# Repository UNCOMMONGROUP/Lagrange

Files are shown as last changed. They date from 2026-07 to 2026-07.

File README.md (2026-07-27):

# Lagrange USB-UART Bridge

An open-source USB CDC-ACM to UART bridge built around the Renesas RA2L2 MCU.

## Why another USB-UART adapter?

Because the cheap ones keep letting us down.

If you have spent any time bringing up embedded hardware, you know the failure
modes: the adapter enumerates fine for an hour and then silently stops passing
data, the COM port vanishes mid-flash and takes the bootloader session with it,
throughput collapses under sustained traffic, or the driver decides today is the
day it does not want to install. Mass-market clone adapters — the CH340-class
parts you find on every marketplace — are cheap for a reason, and when a debug
session depends on the serial link staying up, that cost shows up somewhere
else. We got tired of blaming our own firmware for problems that turned out to
be the adapter, so we built one we could actually trust.

This design is meant to be boring in the best way: stable enumeration, reliable
sustained throughput up to 1.5 Mbps, and behaviour you can reason about because
the firmware is right here in this repository.

## Why an MCU instead of a dedicated bridge chip?

We deliberately did **not** use a fixed-function bridge IC such as the FT232.

A dedicated bridge chip does exactly one thing, and if you need it to do
anything else, you buy a different chip and redesign the board. By building on
the RA2L2 — a general-purpose Arm Cortex-M23 MCU with native USB — the
conversion logic lives in firmware instead of in silicon. The same hardware can
be retargeted to other interfaces: I2C, SPI, CAN, RS-485, or a protocol-aware
debug tool that does more than shuffle bytes. Adding an interface becomes a
firmware release rather than a new product.

It also means the behaviour is inspectable and fixable. If something needs to
change — buffering strategy, flow control, line-coding handling — the source is
in this repository and you can change it. That is not an option with a
closed-function bridge chip.

## Features

- USB 2.0 Full-Speed CDC-ACM (virtual COM port, no vendor driver required)
- Baud rates up to 1.5 Mbps with 0% error at the target clock
- DTC-driven UART path with a 1 ms idle flush, so sustained traffic does not
  drown the CPU in per-byte interrupts
- Live reconfiguration of baud rate, parity, stop bits and data bits via CDC
  `SET_LINE_CODING`
- TX and RX activity LEDs
- USB-C connector with proper CC termination
- ESD protection on both the USB and UART sides
- Molex Pico-Lock connector on the UART side
- 3D-printed (SLS) enclosure; design files included

## Hardware

| Item | Detail |
| --- | --- |
| MCU | Renesas RA2L2 (R7FA2L2074CNH), Arm Cortex-M23 |
| System clock | 48 MHz HOCO — no external crystal required |
| UART | SCI1 |
| USB | Full-Speed device, USB-C receptacle |
| UART connector | Molex Pico-Lock 205338-0004 |
| PCB | 40 × 19 mm, single-sided assembly |

## Repository layout

```
firmware/    e2 studio project (Renesas FSP)
hardware/    schematic, PCB design files, enclosure STEP
```

## Building the firmware

The firmware is an e2 studio project based on the Renesas Flexible Software
Package (FSP). Open the project in e2 studio, run **Generate Project Content**
from the FSP Configurator, and build.

## License

- **Firmware:** MIT — see [LICENSE](LICENSE)
- **Hardware:** CERN-OHL-S v2 — see [LICENSE-hardware](LICENSE-hardware)

Portions of the firmware are provided by the Renesas Flexible Software Package
and are licensed under BSD-3-Clause by Renesas Electronics Corporation; the
original copyright notices are retained in those files.

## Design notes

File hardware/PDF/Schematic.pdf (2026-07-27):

# Molex Picoblade ²KR1

# USB-C / Data + Power

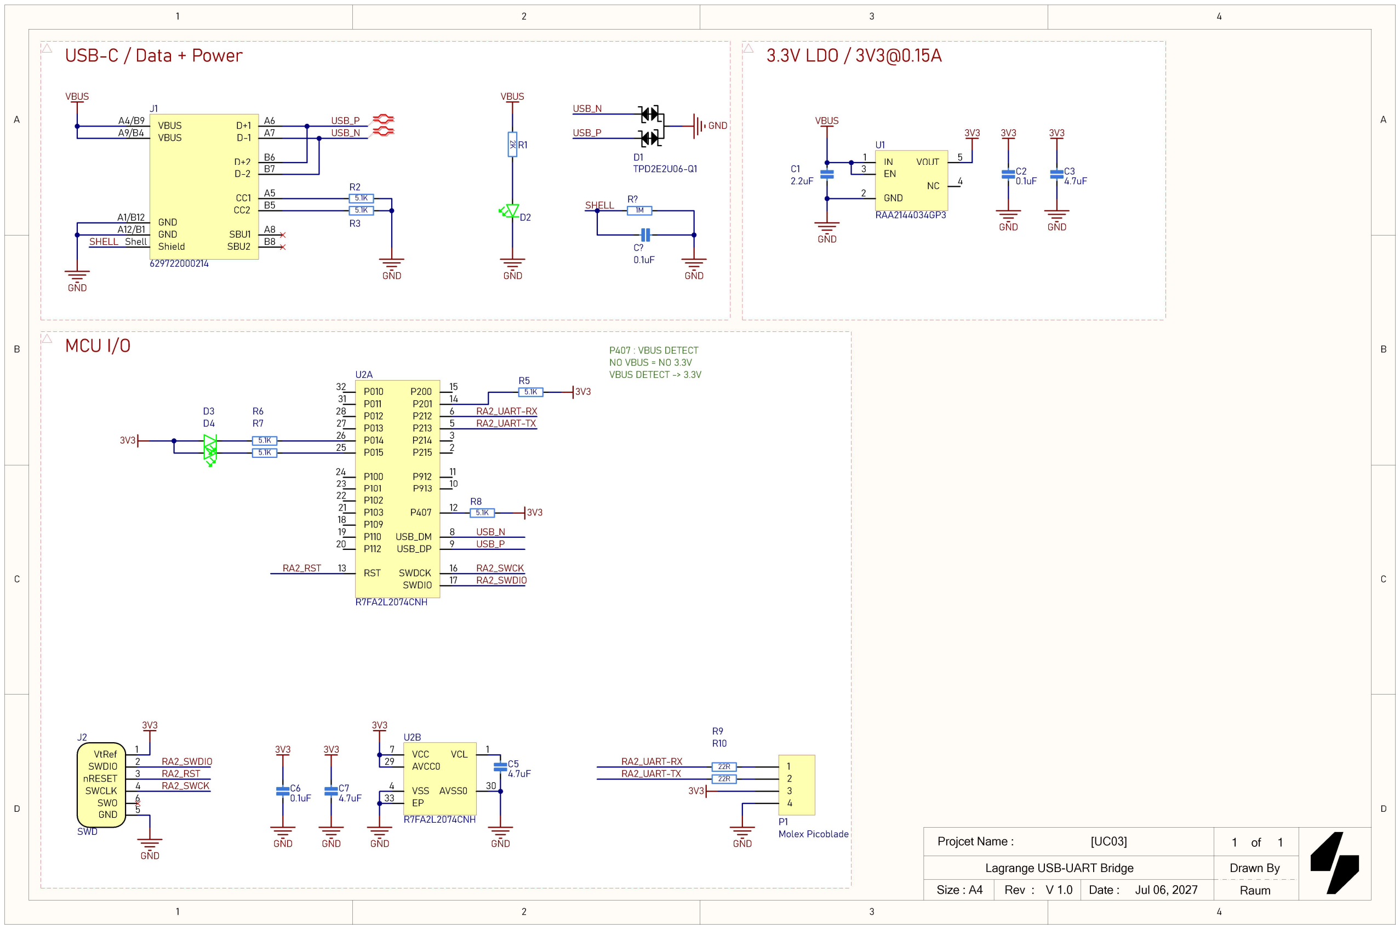
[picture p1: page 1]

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
[UC03] | 1 | 1
V 1.0 | Jul 06, 2027

## Projcet Name :

## Size : A4 Rev :

of

## Date :

## Drawn By

## Raum

## Lagrange USB-UART Bridge

1
2
3
4

P1

D2

GND

VBUS

C1
2.2uF

GND

C2
0.1uF

GND

C3
4.7uF

GND

IN 1

GND 2

EN 3
NC | 4
VOUT | 5

U1

RAA2144034GP3

3V3 | 3V3 | 3V3

GND

5.1K

R2

5.1K
R3

GND

VBUS

VBUS

# MCU I/O

P215 | 2
P214 | 3
P213 | 5
P212 | 6
USB_DM | 8
USB_DP | 9
P913 | 10
P912 | 11
P407 | 12

RST 13

P201 | 14
P200 | 15
SWDCK | 16
SWDIO | 17

P109 18
P110 19
P112 20

P103 21

P102 22

P101 23

P100 24

P015 25

P014 26

P013 27

P012 28

P011 31

P010 32

U2A

R7FA2L2074CNH

VCL 1

VSS 4

VCC 7
AVCC0 29

AVSS0 30
EP 33

U2B

R7FA2L2074CNH

3V3

GND | GND C5 4.7uF

C6
0.1uF

GND

C7
4.7uF

GND

3V3 | 3V3 VtRef | 1
SWDIO | 2
nRESET | 3
SWCLK | 4
GND | 5
SWO | 6

J2

SWD

3V3

GND

RA2_SWDIO

RA2_SWCK

RA2_RST

RA2_RST
RA2_SWDIO

RA2_SWCK

GND A1/B12

VBUS A4/B9

CC1 | A5
D+1 | A6
D-1 | A7
SBU1 | A8

VBUS A9/B4

GND A12/B1

CC2 | B5
D+2 | B6
D-2 | B7
SBU2 | B8 Shield Shell

J1

629722000214

USB_P
USB_N

USB_P

USB_N

5.1K | 3V3

R8

RA2_UART-TX

RA2_UART-RX

# 3.3V LDO / 3V3@0.15A

GND
USB_P

USB_N

RA2_UART-TX

RA2_UART-RX | 22R R9

22R

R10

3V3

GND

5.1K | 3V3

R5

D1
TPD2E2U06-Q1
3V3 | 5.1K

R6

5.1K

R7

D3
D4

1M

R?

C?
0.1uF

SHELL

SHELL

GND

P407 : VBUS DETECT
NO VBUS = NO 3.3V
VBUS DETECT -> 3.3V

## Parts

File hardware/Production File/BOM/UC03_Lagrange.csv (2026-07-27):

Designator | Name | Description | Footprint | LibRef | Quantity
C1 | 2.2uF | Ceramic MLCC CAP | CAPC1608X90N_2 | CAP_MLCC | 1
C2, C4, C6 | 0.1uF | Ceramic MLCC CAP | CAPC1608X90N_2 | CAP_MLCC | 3
C3, C5, C7 | 4.7uF | Ceramic MLCC CAP | CAPC1608X90N_2 | CAP_MLCC | 3
D1 | TPD2E2U06-Q1 | Automotive Dual-Channel High-Speed ESD Protection Device | SC70_3 | TPD2E2U06-Q1 | 1
D2, D3, D4 | GRN | CHIP LED GREEN | LED-0603-GREEN | LED_GREEN | 3
J1 | 629722000214 | WR-COM USB 2.0 Type C Receptacle Horizontal SMT | 629722000214 | 629722000214 | 1
P1 | JST PA | Header, 4-Pin | 2053380004 | Header 4 | 1
R1 | 2K | Chip FIlm Resistor | RESC1608X55N_2 | R_Film_Chip | 1
R2, R3, R5, R6, R7, R8 | 5.1K | Chip FIlm Resistor | RESC1608X55N_2 | R_Film_Chip | 6
R4 | 1M | Chip FIlm Resistor | RESC1608X55N_2 | R_Film_Chip | 1
R9, R10 | 22R | Chip FIlm Resistor | RESC1608X55N_2 | R_Film_Chip | 2
U1 | RAA2144034GP3 | Low Iq Current LDO Regulator with Fixed 3.3V Output | SOT23-5 | RAA2144034GP3 | 1
U2 | R7FA2L2074CNH | Ultra low power 48 MHz Arm¢ç Cortex¢ç-M23 core, up to 128-KB code flash memory, 16-KB SRAM, USB 2.0 Full-Speed module (USBFS), USB Type-C¢ç interface (USBCC), 12-bit A/D Converter, Security and Safety features | ALLEGRO QFN-32 ET | R7FA2L2074CNH | 1

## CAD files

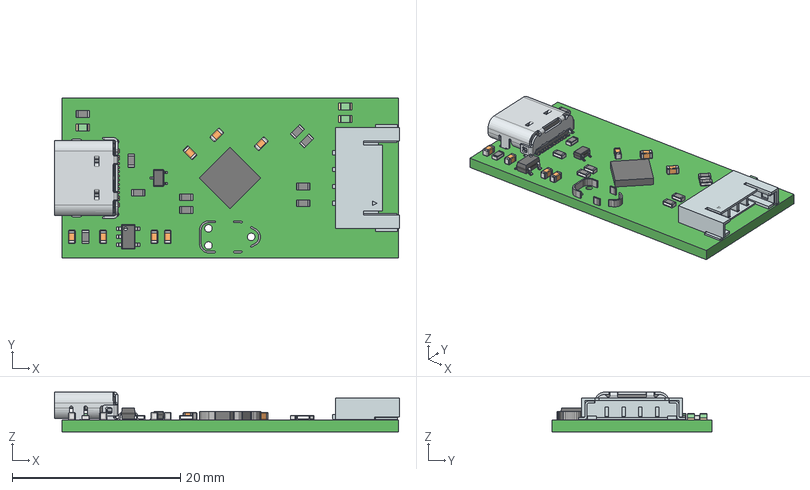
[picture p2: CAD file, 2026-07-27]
hardware/3D STEP/UC03_Lagrange.step
41.0 x 19.0 x 4.75 mm
LED 0603 APT1608 GREEN x 3
BODY-SOT
LEAD-SOT x 3
PIN1-ID
Extruded x 5
SOT23-5
629722000214_Housing
629722000214_Pin1_Top
629722000214_Pin4_Bottom
629722000214_Pin4_Top x 2
629722000214_Pin1_Bottom
629722000214_Pin3_Bottom
629722000214_Pin3_Top
629722000214_Pin2_Top
629722000214_Pin2_Bottom
629722000214_Pin1_Top_mir
629722000214_Pin1_Bottom_mir
629722000214_Pin2_Top_mir
629722000214_Pin2_Bottom_mir
629722000214_Pin3_Top_mir
629722000214_Pin3_Bottom_mir
629722000214_Pin4_Bottom_mir
629722000214_Shielding2
629722000214_Shielding

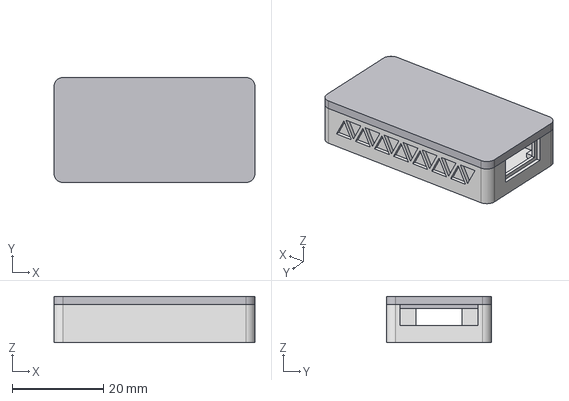
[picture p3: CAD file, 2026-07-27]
hardware/Enclouser/Lagrange_case.step
44.0 x 23.0 x 10.1 mm
tray
lid

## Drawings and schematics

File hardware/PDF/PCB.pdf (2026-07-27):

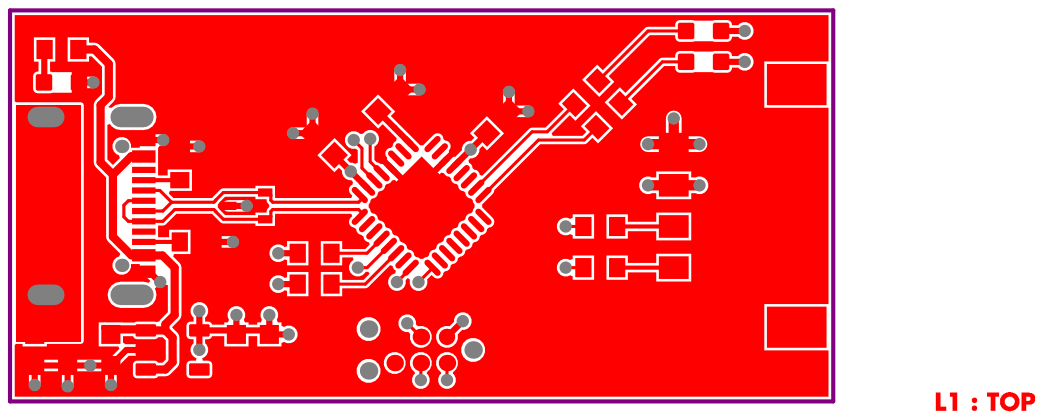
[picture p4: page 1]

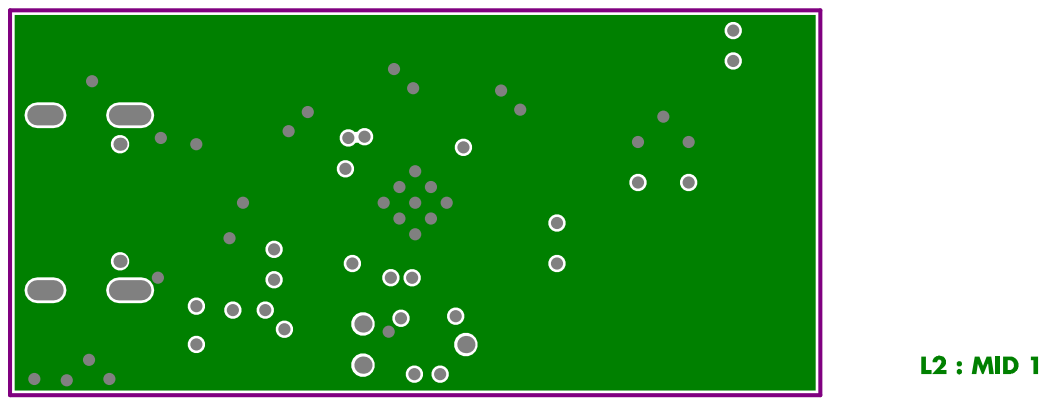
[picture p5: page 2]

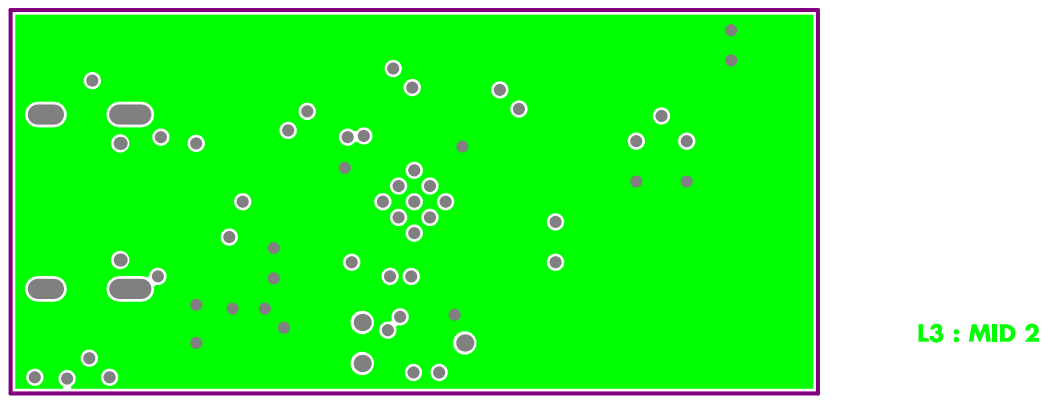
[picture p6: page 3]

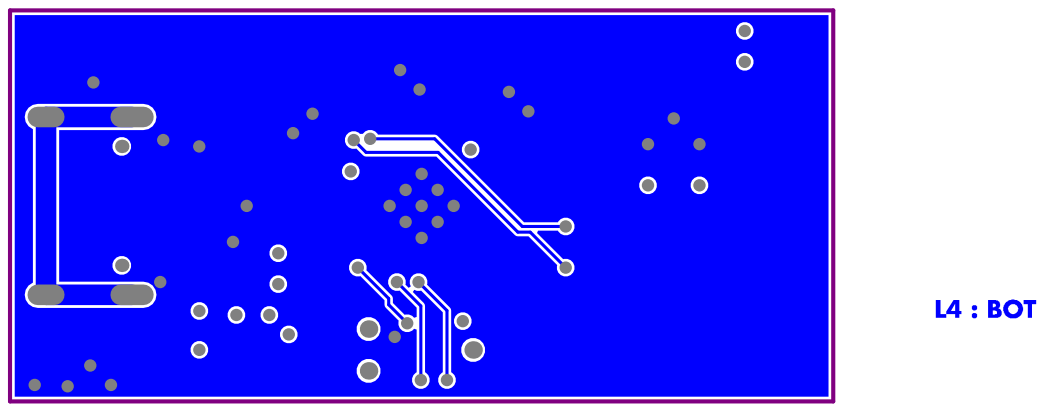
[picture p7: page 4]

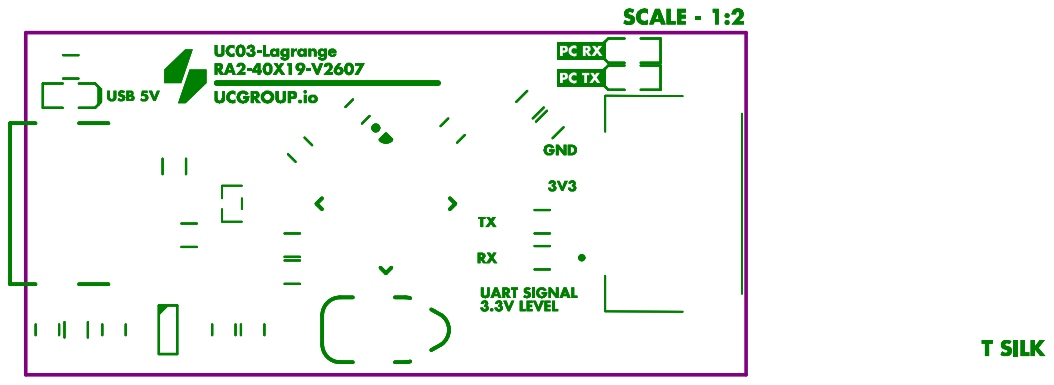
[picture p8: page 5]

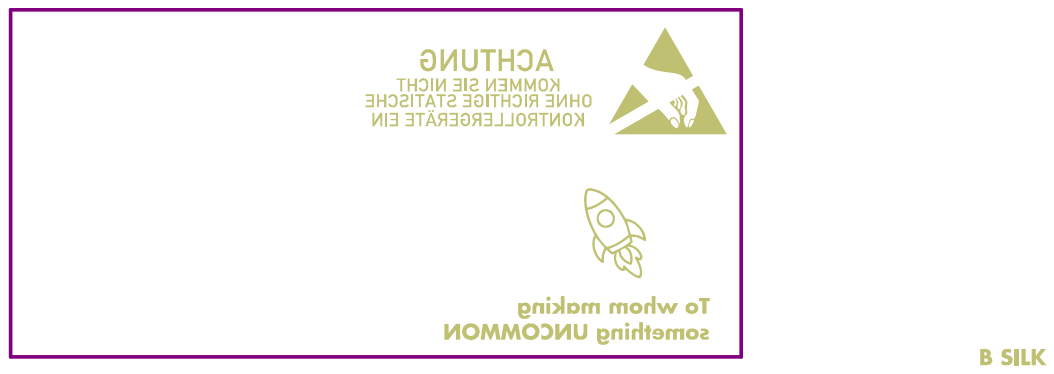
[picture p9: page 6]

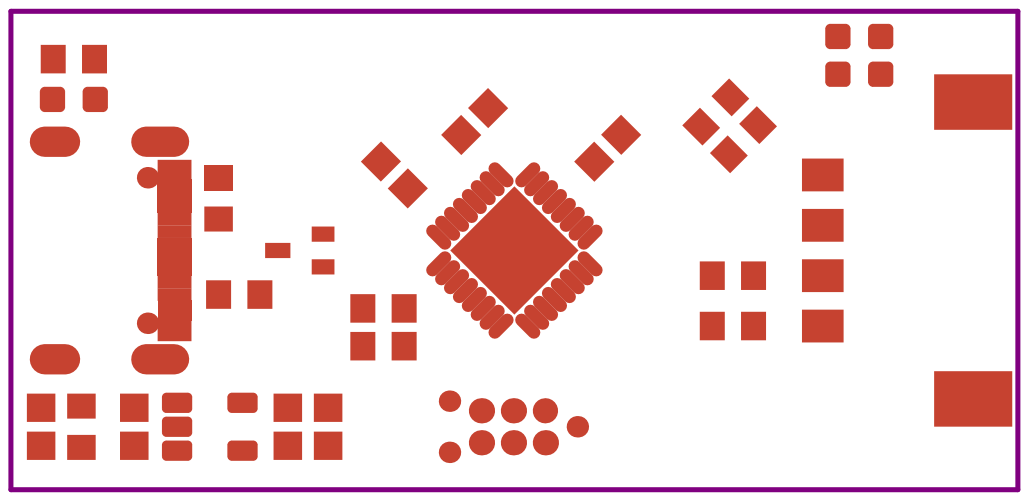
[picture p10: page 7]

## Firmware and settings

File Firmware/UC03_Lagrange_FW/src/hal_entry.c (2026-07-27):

/***********************************************************************************************************************
 * UC03 "Lagrange" — USB CDC-ACM to UART bridge on Renesas RA2L2 (R7FA2L2074CNH)
 *
 * Architecture for sustained 1.5 Mbps operation:
 *   - DTC on SCI1 RX/TX removes the per-byte CPU interrupt (one interrupt per
 *     512-byte chunk on RX, one per packet on TX)
 *   - A 1 ms AGT tick performs an "idle flush": whatever has arrived so far is
 *     forwarded even if the chunk is not full, bounding latency at ~1 ms
 *     (the same idea as the FTDI latency timer)
 *   - RX uses a 512-byte ping-pong pair; USB IN transfers straight from the
 *     filled buffer with no intermediate copy
 *
 * Required FSP stacks (instance and callback names must match this file):
 *   - g_basic0 : USB PCDC (r_usb_pcdc + r_usb_basic), peripheral, Full-Speed
 *   - g_uart0  : UART (r_sci_uart) on SCI1, callback = uart0_cb
 *                + DTC driver for transmission (r_dtc, SCI1 TXI)
 *                + DTC driver for reception    (r_dtc, SCI1 RXI)
 *   - g_timer0 : Timer, Low-Power (r_agt) ch0, periodic 1 ms, callback = agt0_cb
 *
 * Suggested interrupt priorities (Cortex-M23, 0 = highest):
 *   SCI1 RXI = 0 / SCI1 TXI, TEI, ERI = 1 / USBFS INT = 2 / AGT0 = 3
 *
 * Copyright (c) Uncommon Group. SPDX-License-Identifier: MIT
 **********************************************************************************************************************/
#include "hal_data.h"
#include <string.h>

/* Provided by usb_descriptor.c */
extern void usb_descriptor_serial_init(void);

/*======================================================================================================
 * Configuration
 *====================================================================================================*/
#define RX_CHUNK            (512U)                  /* UART RX DTC chunk size (two buffers = 1 KB) */
#define USB_BULK_MPS        (64U)                   /* Full-Speed Bulk max packet size */
#define LINE_CODING_LENGTH  (7U)

#define LED_TX_PIN          (BSP_IO_PORT_01_PIN_12) /* USB to UART activity */
#define LED_RX_PIN          (BSP_IO_PORT_01_PIN_03) /* UART to USB activity */
#define LED_ON              (BSP_IO_LEVEL_LOW)      /* active-low LED; swap if the board is wired the other way */
#define LED_OFF             (BSP_IO_LEVEL_HIGH)
#define LED_HOLD_MS         (30U)                   /* LED hold time after activity [ms] */

/*======================================================================================================
 * State
 *====================================================================================================*/
/* --- UART RX ping-pong buffers, filled by DTC --- */
static uint8_t           g_rx_buf[2][RX_CHUNK];
static volatile uint16_t g_rx_len[2] = {0, 0};      /* 0 = empty, >0 = bytes waiting for USB */
static volatile uint8_t  g_rx_fill_idx = 0;         /* buffer DTC is filling (changed in ISR/critical section) */
static uint8_t           g_rx_send_idx = 0;         /* next buffer to send over USB (main loop only) */
static uint8_t           g_usb_tx_src  = 0;         /* buffer currently in flight (zero-copy source) */

/* --- diagnostic counters --- */
static volatile uint32_t g_rx_overrun_bytes = 0;    /* bytes dropped because USB could not keep up */
static volatile uint32_t g_rx_char_stray    = 0;    /* bytes arriving with no read armed; should stay 0 */

/* --- USB buffers and flags --- */
static uint8_t           g_usb_rx_buf[USB_BULK_MPS];
static volatile bool     g_usb_configured = false;
static volatile bool     g_usb_suspended  = false;
static volatile bool     g_usb_rx_armed   = false;
static volatile bool     g_usb_tx_busy    = false;
static volatile bool     g_uart_tx_busy   = false;

/* --- timer tick and LED state --- */
static volatile bool     g_tick_1ms   = false;
static volatile uint32_t g_led_tx_ms  = 0;
static volatile uint32_t g_led_rx_ms  = 0;

static usb_pcdc_linecoding_t g_line_coding =
{
    .dw_dte_rate   = 115200,
    .b_char_format = 0,
    .b_parity_type = 0,
    .b_data_bits   = 8,
};

/*======================================================================================================
 * UART callback (set g_uart0 "Callback" property to uart0_cb)
 *====================================================================================================*/
void uart0_cb (uart_callback_args_t * p_args)
{
    switch (p_args->event)
    {
        case UART_EVENT_RX_COMPLETE:            /* DTC filled RX_CHUNK: one interrupt per chunk */
        {
            uint8_t cur = g_rx_fill_idx;
            uint8_t nxt = cur ^ 1U;

            if (0U == g_rx_len[nxt])
            {
                /* hand the full buffer to the sender and re-arm on the other one (lossless: still inside the ISR) */
                g_rx_len[cur] = RX_CHUNK;
                g_rx_fill_idx = nxt;
                (void) R_SCI_UART_Read(&g_uart0_ctrl, g_rx_buf[nxt], RX_CHUNK);
            }
            else
            {
                /* both buffers pending: USB is behind, so drop this chunk and re-arm on the same buffer */
                g_rx_overrun_bytes += RX_CHUNK;
                (void) R_SCI_UART_Read(&g_uart0_ctrl, g_rx_buf[cur], RX_CHUNK);
            }
            break;
        }

        case UART_EVENT_TX_COMPLETE:
        {
            g_uart_tx_busy = false;
            break;
        }

        case UART_EVENT_RX_CHAR:                /* byte arrived with no read armed; should not happen by design */
        {
            g_rx_char_stray++;
            break;
        }

        /* receive errors are ignored; the driver clears them and the DTC read stays armed */
        default:
            break;
    }
}

/*======================================================================================================
 * AGT 1 ms callback (set g_timer0 "Callback" property to agt0_cb)
 *====================================================================================================*/
void agt0_cb (timer_callback_args_t * p_args)
{
    if (TIMER_EVENT_CYCLE_END == p_args->event)
    {
        g_tick_1ms = true;
    }
}

/*======================================================================================================
 * Start or reset the RX pipeline; call right after the UART is opened
 *====================================================================================================*/
static void uart_rx_pipeline_start (void)
{
    g_rx_len[0]   = 0;
    g_rx_len[1]   = 0;
    g_rx_fill_idx = 0;
    g_rx_send_idx = 0;
    (void) R_SCI_UART_Read(&g_uart0_ctrl, g_rx_buf[0], RX_CHUNK);
}
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

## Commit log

2026-07-27 Initial commit: HW Material Upload
    [Pick Place for UC03_Lagrange.csv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]
2026-07-27 Add Lagrange firmware, README, and gitignore
    [Lagrange_case.step]
